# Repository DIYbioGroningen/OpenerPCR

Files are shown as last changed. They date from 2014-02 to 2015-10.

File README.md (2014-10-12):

OpenerPCR is a project by DIYbio Groningen to create an open PCR machine (also called a thermocycler). OpenerPCR is inspired by the OpenPCR project.

 * [Bill of materials](bill_of_materials.md)

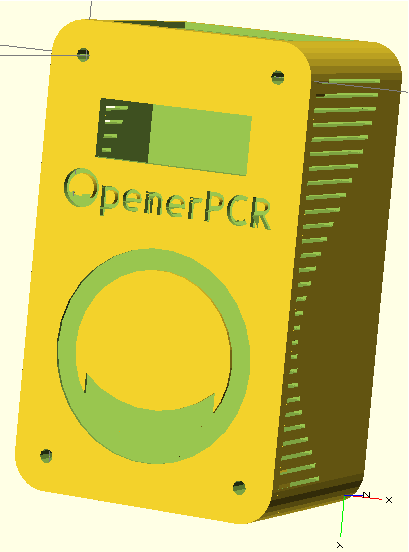
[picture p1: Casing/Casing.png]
Casing

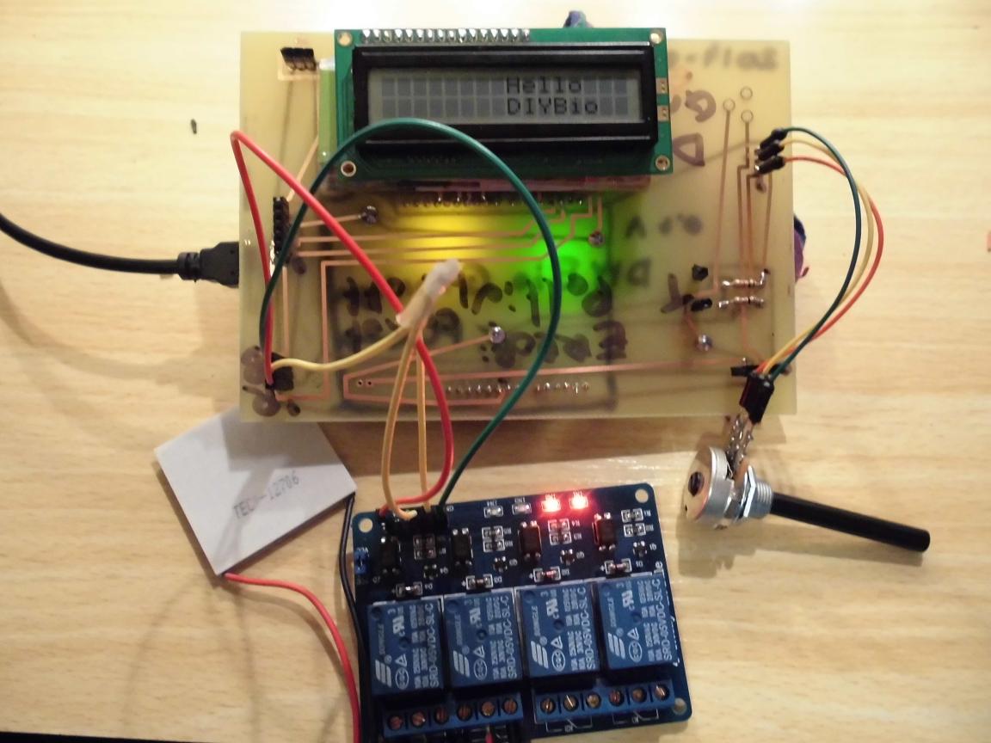
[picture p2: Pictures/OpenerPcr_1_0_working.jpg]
Working

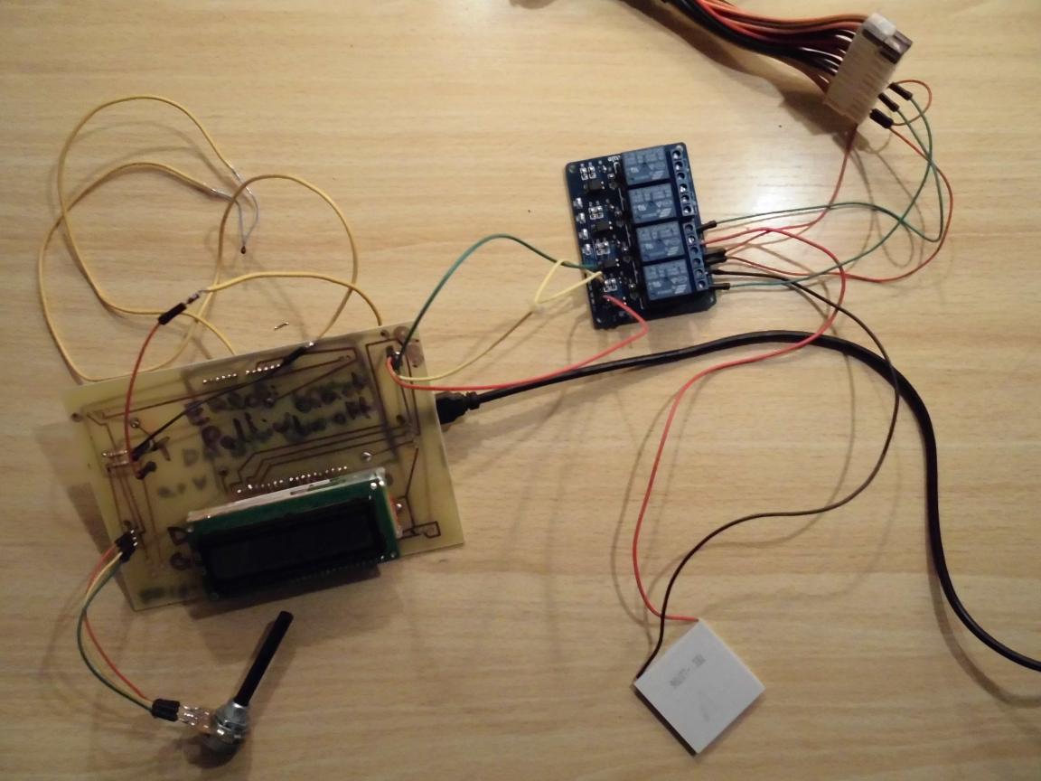
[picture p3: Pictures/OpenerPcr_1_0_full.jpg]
Full

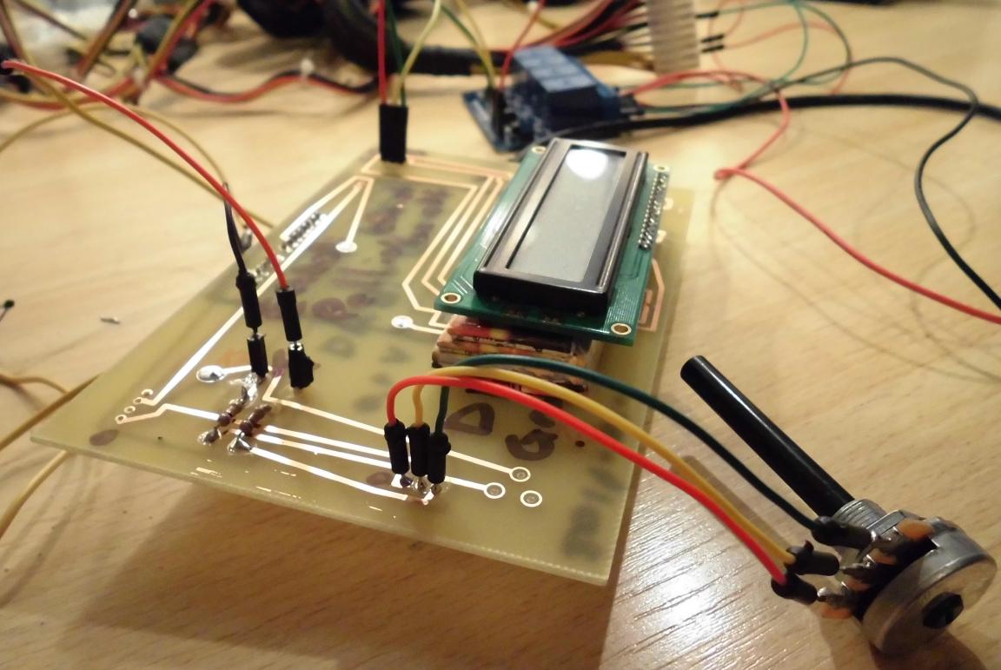
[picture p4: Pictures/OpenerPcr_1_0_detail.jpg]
Detail


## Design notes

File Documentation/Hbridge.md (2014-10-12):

# H bridge

The Pelter elements needs direct current. The direction of that current determines if a Peltier side cools or heats. The OpenerPCR needs to be able to let the Peltier cool and heat, so the current through the Peltier needs to be reversed. An H bridge can be used to achieve this.

There are multiple ways to create an H bridge: amongst others, using relays and using transistors. For the OpenerPCR project we chose to use relays (for now).

```
Signal
  |
+-+--+
|    |
|    A-  
|    |
|    B-
|    |
|    C-
|    |
+-+--+
  |
 GND
```

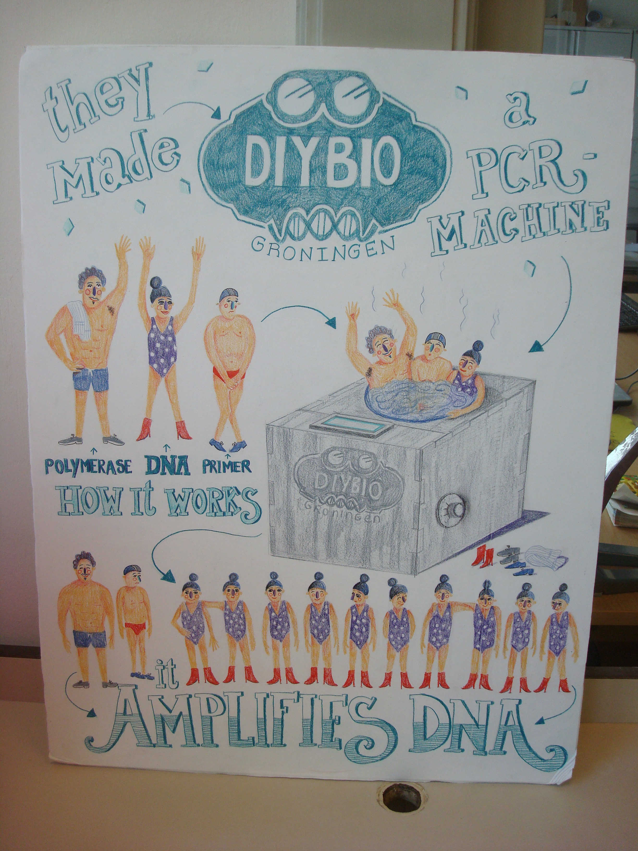
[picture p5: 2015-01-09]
Pictures/DIYBio_OpenerPCR_illustration.JPG

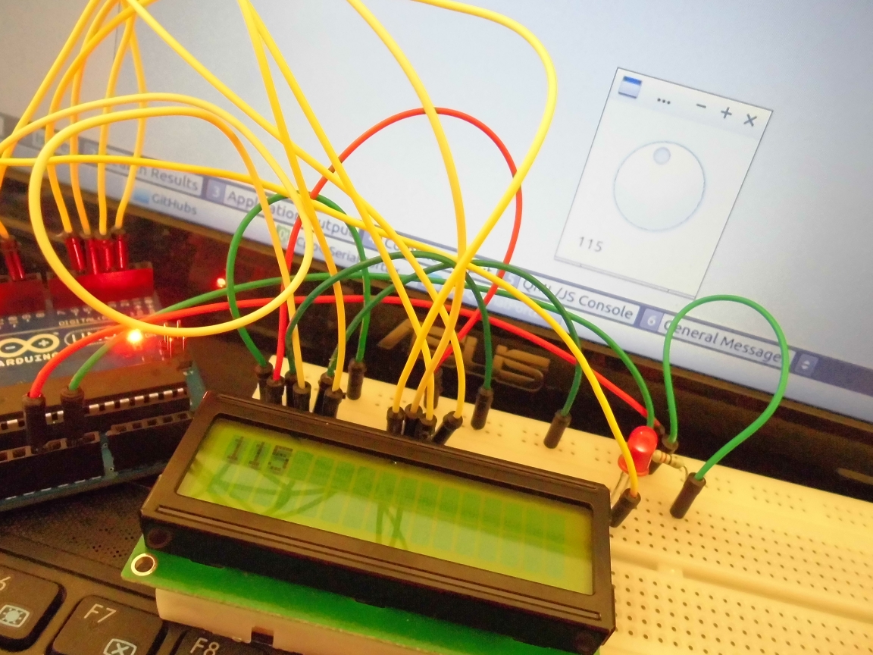
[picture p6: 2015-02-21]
Misc/Communication20141222.jpg

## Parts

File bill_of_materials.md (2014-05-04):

Bill Of Materials 
=================

Consist of components and autonomous parts

Components
----------

# Active/passive components

<table>
  <tr>
    <td>#</td><td>Brand official </td><td>Serial #</td><td>Description</td><td>SMD</td><td>What we really bought</td>
  </tr>
  <tr>
    <td>2</td><td>Yageo</td><td>SQP10AJB-4R7</td><td>Resistor, 4.7 Ohm, 10 W</td><td>No</td><td><a href="http://www.conrad.nl/ce/nl/product/411850/Draadweerstand-11W-47Ohm-Axiaal-Hoge-belasting-47-11-W-10-">Conrad</a></td>
  </tr>
  <tr>
    <td>1</td><td>Panasonic</td><td>ERG-2SJ160</td><td>Resistor, 16 Ohm </td><td>No</td><td>3 resistors circuit: (10 + 22) + 10</td>
  </tr>
  <tr>
    <td>2</td><td>Yageo</td><td>MFP-25BRD52-2K2</td><td>Resistor, 2.2k Ohm, 0.1%</td><td>No</td><td>Resistor, 2.2k Ohm, 1%</td>
  </tr>
  <tr>
    <td?1</td><td>Tyco</td><td>282834-6</td><td>Terminal block, 6 connector</td><td>No</td><td> </td>
  </tr>
  <tr>
    <td>2</td><td>Panasonic</td><td>ERJ-3GEYJ332V</td><td>Resistor, 3.3k Ohm</td><td>Yes</td><td>3 resistors circuit: (22K + 22K) + 22</td>
  </tr>
  <tr>
    <td>4</td><td>Panasonic</td><td>ERJ-3GEYJ102V</td><td>Resistor, 1k Ohm</td><td>Yes</td><td>As is</td>
  </tr>
  <tr>
    <td>1</td><td>Panasonic</td><td>ERG-1SJ510</td><td>Resistor, 51 Ohm, 1 W</td><td>No</td><td><a href="http://www.okaphone.com/artikel.asp?id=468110 Okaphone RC56E">Okaphone</a>: Resistor, 56 Ohm, 1 W</td>
  </tr>
  <tr>
    <td>1</td><td>Fairchild</td><td>RFD3055LE</td><td>Transistor, MOSFET N-Ch</td><td>No</td><td>  </td>
  </tr>
  <tr>
    <td>1</td><td>Microchip</td><td>MCP3551-E/SN</td><td>ADC, 22 bit</td><td>No</td><td><a href="ttp://www.okaphone.com/artikel.asp?id=476677 Okaphone MCP3551-E/MS">Okaphone</a></td>
  </tr>
  <tr>
    <td>1</td><td> Panasonic</td><td> ECA-1CM332</td><td> Capacitor, 3300 uF</td><td> No</td><td><a href="http://www.conrad.nl/ce/nl/product/421937/Panasonic-Radiale-condensator-serie-FC-EEUFC1C332-x-h-125-mm-x-35-mm-Rastermaat-5-mm-3300-F-16-V">Conrad</a></td>
  </tr>
  <tr>
    <td>1</td><td>Panasonic</td><td>ECA-1CM102</td><td>Capacitor, 1000 uF</td><td>No</td><td><a href="http://www.conrad.nl/ce/nl/product/441666/Panasonic-Radiale-elektrolytische-condensator-ECA-ECA1CM102-x-l-10-mm-x-16-mm-Rastermaat-5-mm-1000-F-16-V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">Conrad</a></td>
  </tr>
  <tr>
    <td>1</td><td>ST</td><td>VNH3SP30</td><td>H-Bridge IC</td><td>Yes</td><td><a href="http://www.okaphone.com/artikel.asp?id=476678 Okaphone VNH3SP30-E">Okaphone</a></td>
  </tr>
  <tr>
    <td>1</td><td>Custom</td><td></td><td>Peltier, Qmax = 84 W, dT = 78 K, Imax = 7.8 A</td><td>No</td><td><a href="http://www.okaphone.com/artikel.asp?id=471426">Okaphone (PELTIER 21)</a>: Qmax = 71 W, dT = 67 K, Imax = 8.0 A</td>
  </tr>
  <tr>
    <td>1</td><td>US Sensor</td><td>USP11553 rev none</td><td>Thermistor / PTC</td><td>No</td><td>HEISSLEITER S861/5K/1%/F40, 541-086-23, 500670, EAN: ...46 6996 O (the character capital-O)  3/18, 10671-348, 9549804009 546432717</td>
  </tr>
  <tr>
    <td>1</td><td>Custom</td><td> </td><td>Kapton Heater, 25 W, 11.3 V</td><td>No</td><td> </td>
  </tr>
</table>

#Autonomous parts

Things to connect components with/on/to

<table>
  <tr>
    <td># </td><td>Part</td><td>What we really bought
  </tr>
  <tr>
    <td>1</td><td>Arduino Uno</td><td>As is</td>
  </tr>
  <tr>
    <td>1</td><td>MicroATX power supply, 200 W, 14 A on 12 V rail, fan temperature control disabled, 24 pin ATX connector only</td><td>Scavanged</td>
  </tr>
  <tr>
    <td>1</td><td>Ribbon cable, 16 pin, female - female, 24"</td><td>?Hive5</td>
  </tr>
  <tr>
    <td>1</td><td>LCD, HD44780 compatible, 20 chars, 4 rows, blue backlight</td><td> <a href="http://www.okaphone.com/artikel.asp?id=421513 Okaphone LCD1602LC">Okaphone</a>: LCD 16 chars, 2 rows</td>
  </tr>
  <tr>
    <td>1</td><td>PCB</td><td>Etched, in possession</td>
  </tr>
  <tr>
    <td>1</td><td>USB Cable, A to B, 6 feet</td><td>In possession</td>
  </tr>
  <tr>
    <td>1</td><td>PSU Power Cord, USA plug, 6 feet</td><td> </td>
  </td>
</table>

Original wiring of HD44780 compatible LCD display OpenPCR used [http://en.wikipedia.org/wiki/Hitachi_HD44780_LCD_controller#Architecture Wikipedia]:

```
1    Ground
2    VCC (+3.3 to +5V)
3    Contrast adjustment (VO)
4    Register Select (RS). RS=0: Command, RS=1: Data
5    Read/Write (R/W). R/W=0: Write, R/W=1: Read
6    Clock (Enable). Falling edge triggered
7    Bit 0 (Not used in 4-bit operation)
8    Bit 1 (Not used in 4-bit operation)
9    Bit 2 (Not used in 4-bit operation)
10    Bit 3 (Not used in 4-bit operation)
11    Bit 4
12    Bit 5
13    Bit 6
14    Bit 7
15    Backlight Anode (+)
16    Backlight Cathode (-)
```

The LCD that was ordered has exactly the same interface (that is: its pins serve exactly the same function)

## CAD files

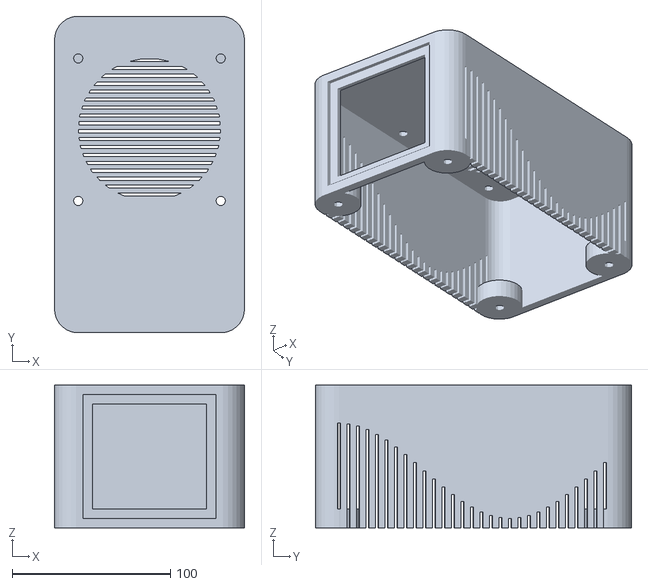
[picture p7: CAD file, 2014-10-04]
Casing/BackPanel.stl
120.0 x 199.8 x 90.0

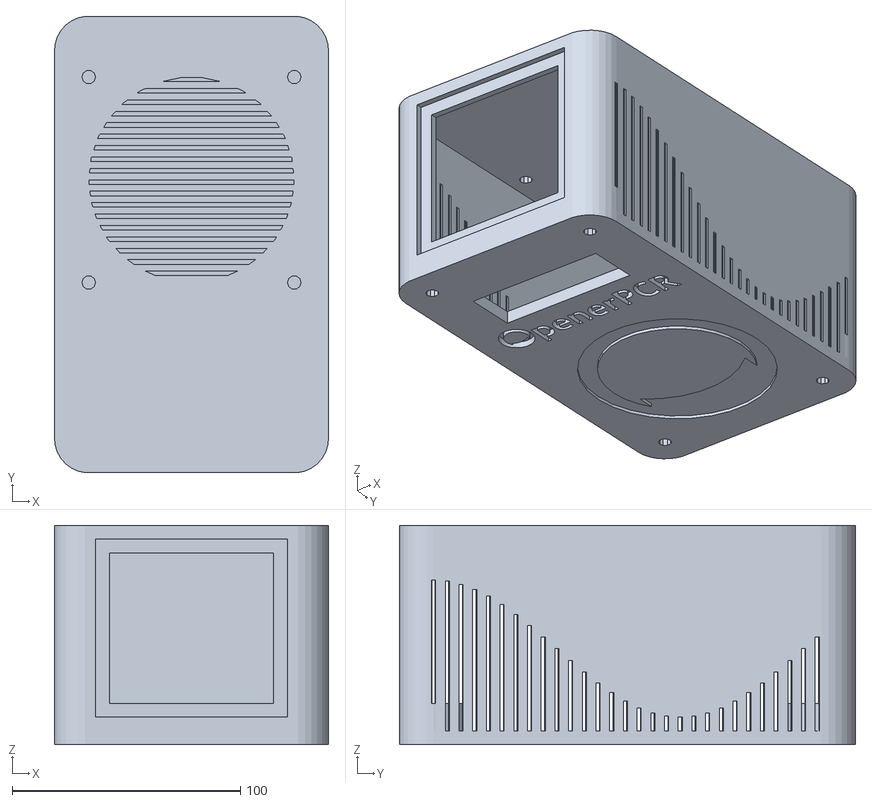
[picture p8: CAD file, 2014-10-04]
Casing/OpenerPCR.stl
120.0 x 199.8 x 96.0

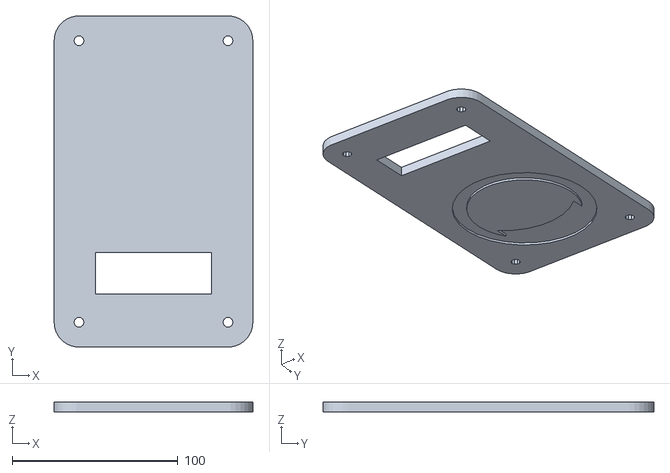
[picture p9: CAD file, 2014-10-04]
Casing/FrontPanel.stl
120.0 x 199.8 x 6.00

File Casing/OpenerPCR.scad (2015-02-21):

// OpenerPCR case.
// Ver 0.3.1
// by DIYbio Groningen
include <OpenrPCR_logo.scad>

//Build options
has_front = true;
has_back = false;
has_components = true;
has_leds = true;

W =  90; //Inner width of the casing in mm
H = 170; //Inner height of the casing in mm
Z =  90; //Inner depth of the casing in mm
Tk = 3;  //Thickness of casing material in mm, e.g. perspex is 3 mm
cr = 15; //Corner radius in mm
total_H = H+2*cr; //Outer height of the casing in mm
total_W = W+2*cr; //Outer width of the casing in mm
LCD_H = 25; //Width of the LCD display in mm
LCD_W = 70; //Height of the LCD display in mm
LCD_D = 19; //Depth of the LCD display in mm

shr = 3; //Screw hole radius in mm
offset = cr < 1 ? Tk+shr : 0; //The least distance a screw hole must be from the side
fd = 90; //Fan diameter in mm
Pcb_W_outer =  90; //Outer width of PCB in mm, the width of the box of air the PCB is in
Pcb_H_outer = 170; //Outer height of PCB in mm, the height of the box of air the PCB is in
Pcb_D_outer =  40; //Outer depth of PCB in mm, the depth of the box of air the PCB is in
Pcb_W = Pcb_W_outer; //Width of PCB in mm, the width of the box of air the PCB is in
Pcb_H = Pcb_H_outer; //Height of PCB in mm, the height of the box of air the PCB is in
Pcb_D = 2; //Depth of PCB in mm, the depth of the box of air the PCB is in
led_radius = 1.5; //Radius of an LED in mm
led_spacing = 10; //Distance between two LEDs in mm

module led_hole(){
  cylinder(h=4*Tk, r=led_radius);
}

module screw_hole(){
  cylinder(h=4*Tk, r=shr);
}

module screw_holder(){
  difference(){
    cylinder(h=4*Tk, r=cr);
    translate([0,0,-Tk]){
      cylinder(h=6*Tk, r=shr);
    }
  }  
}

module LCD_hole(){
  cube(size = [LCD_W,LCD_H,4*Tk]);
}

module panel(){
  minkowski(){
    cube([W,H,Tk]);
    // rounded corners
    cylinder(h=Tk,r=cr);
  }
}

module OpenerPCR_logo()
{
  difference(){
    cylinder(Tk,W/2,W/2);
    translate([0,0,-Tk]){
      cylinder(4*Tk,W/2.5,W/2.5);
    }
  }
  difference(){
    translate([-W/3,-W/10,0]){
      cube([W/1.5,W/2,Tk]);
    }
    translate([0,-W/4,-Tk]){
      cylinder(4*Tk,W/2,W/2);
    }
    translate([-W/3,W/2,-Tk]){
      cylinder(4*Tk,W/6,W/6);
    }
    translate([W/3,W/2,-Tk]){
      cylinder(4*Tk,W/6,W/6);
    }
  }
}

module plus_symbol(){
	cube([1,led_radius,Tk]);
	rotate([0,0,90]){
		cube([1,led_radius,Tk]);
	}
}

module power_symbol(){
	cylinder(Tk,led_radius*2,led_radius*2);
	difference(){
    	translate([0,0,-Tk]){
      	cylinder(Tk,led_radius*2,led_radius*2);
    	}
	}
	translate([-0.5,-led_radius*3,0]){
		cube([1,led_radius*2,Tk]);
	}
}

module front_panel(){
  difference(){  
    panel();
    // LCD window
    translate([(W-LCD_W)/2,0.1*H,-Tk]){
      LCD_hole();  
    }
    // Screw-holes
    translate([offset,offset,-Tk]){ // top-left
      screw_hole();  
    }
    translate([W-offset,offset,-Tk]){ // top-right
      screw_hole();    
    }
    translate([offset,H-offset,-Tk]){ // bottom-left
      screw_hole();  
    }
    translate([W-offset,H-offset,-Tk]){ // bottom-left
      screw_hole();
    }
    translate([W/2,H/1.4,-0.5*Tk]){
      OpenerPCR_logo();
    }
    if (has_leds) {
      translate([(W/2) +           0,(H/1.4) +           0,-0.5*Tk]){ led_hole(); } //Center Center
      translate([(W/2) +           0,(H/1.4) + led_spacing,-0.5*Tk]){ led_hole(); } //Center Top
      translate([(W/2) +           0,(H/1.4) - led_spacing,-0.5*Tk]){ led_hole(); } //Center
      translate([(W/2) - led_spacing,(H/1.4) +           0,-0.5*Tk]){ led_hole(); } //Left top
      translate([(W/2) - led_spacing,(H/1.4) - led_spacing,-0.5*Tk]){ led_hole(); } //Left bottom
      translate([(W/2) + led_spacing,(H/1.4) +           0,-0.5*Tk]){ led_hole(); } //Right top
      translate([(W/2) + led_spacing,(H/1.4) - led_spacing,-0.5*Tk]){ led_hole(); } //Right bottom
      /*

     5V          5V
     |           |
     O  +--O--+  O
     |  |     |  |
     |  | MMM |  |
     +--+-MMM +--+
     |  | MMM |  |
     |  |     |  |
     O  +--O--+  O
     |           |
     GND        GND

      */
      difference() { translate([(W/2) - (1.0 * led_spacing),(H/1.4) - (0.5 * led_spacing),-0.5*Tk]){ cube([2 * led_spacing,1,Tk]); }} //Center line
      difference() { translate([(W/2) - (0.25 * led_spacing),(H/1.4) - (0.75 * led_spacing),-0.5*Tk]){ cube([0.5 * led_spacing,0.5 * led_spacing,Tk]); }} //Motor

      difference() { translate([(W/2) - (0.5 * led_spacing),(H/1.4) - led_spacing,-0.5*Tk]){ cube([led_spacing,1,Tk]); }} //Top line
      difference() { translate([(W/2) - (0.5 * led_spacing),(H/1.4) +           0,-0.5*Tk]){ cube([led_spacing,1,Tk]); }} //Bottom line
      difference() { translate([(W/2) - (0.5 * led_spacing),(H/1.4) - led_spacing,-0.5*Tk]){ cube([1,led_spacing + 1,Tk]); }} //Left line
      difference() { translate([(W/2) + (0.5 * led_spacing),(H/1.4) - led_spacing,-0.5*Tk]){ cube([1,led_spacing + 1,Tk]); }} //Right line

      difference() { translate([(W/2) - (1.0 * led_spacing),(H/1.4) - (1.5 *led_spacing),-0.5*Tk]){ cube([1,2 * led_spacing,Tk]); }} //Left longer 5 V and GND line
      difference() { translate([(W/2) + (1.0 * led_spacing),(H/1.4) - (1.5 *led_spacing),-0.5*Tk]){ cube([1,2 * led_spacing,Tk]); }} //Right longer 5 V and GND line

		difference() { translate([(W/2) +           0,(H/1.4) + (1.75 *led_spacing),-0.5*Tk]){ power_symbol(); }} //power symbol
		difference() { translate([(W/2) - led_spacing,(H/1.4) +           0,-0.5*Tk]) { plus_symbol(); }} //plus symbol
    }
  }
}

module top_hole(){
  union(){
    // Top outer
    translate([Tk,-cr,3*Tk]){
      cube([W-2*Tk,Tk,Z-4*Tk]);
    }
    // Top inner
    translate([3*Tk,-cr,5*Tk]){
      cube([W-6*Tk,4*Tk,Z-8*Tk]);
    }
  }
}

module fan_holes(){
  // fan exaust
  difference(){
    cylinder(h=4*Tk,r=fd/2);
    for(i = [0:fd/5]){
      translate([-fd/2,-fd/2+(5*i),-Tk]){
        cube([fd,3,8*Tk]);
      }  
    }
  }
  // fan screws
  translate([-fd/2,+fd/2,0]){ // top-left
     screw_hole();  
  }
  translate([fd/2,+fd/2,0]){ // top-right
      screw_hole();    
  }
  translate([-fd/2,-fd/2,0]){ // bottom-left
      screw_hole();  
  }
  translate([fd/2,-fd/2,0]){ // bottom-left
      screw_hole();
  }
}

module air_intake(){
  rotate([0,0,90]){
    for(j=[0:2*Tk]){
      translate([0,-j,0]){
        for(i=[0:H/6]){
            translate([i*2*Tk,cr,Tk]){
                 cylinder(h=cos(i*10)*(Z/3)+(Z/2.5),r=Tk/3);
          }
        }
      }
    }
  }  
}  

// Body
module body(){
  difference(){    
    // Solid
    translate([0,0,Tk])  {
      minkowski() {
          cube([W,H,Z-Tk]);
          // rounded corners
          cylinder(r=cr,h=Tk);
        // al rounded
        //sphere(cr);
      }
    }  
    // Void
    translate([Tk,Tk,0]){
      minkowski() {
          cube([W-2*Tk,H-2*Tk,Z-2*Tk]);
          // rounded corners
          cylinder(r=cr-Tk,h=Tk);
      }
    }
    top_hole();
    air_intake();
    translate([W+cr+(3*Tk),0,0]){
      air_intake();
    }
    translate([W-fd/2,H/1.5,Z-2*Tk]){
    fan_holes();
    }
  }
  difference(){
    union(){
      translate([0,0,Tk]){
        screw_holder();
      }
      translate([W,0,Tk]){
        screw_holder();
      }  
      translate([W,H,Tk]){
        screw_holder();
      }
      translate([0,H,Tk]){
        screw_holder();
      }
    }
    top_hole();
  }
}



//Building
if (has_front)
{
   //Complete casing
  difference(){
    translate([0,0,-Tk]){
      front_panel();
    }
    translate([W/2,H/3,0]){
      rotate([180,0,0]){
        scale([0.5,0.5,1]){
          OpenerPCR_full_logo(10);
        }
      }
    }
  }
}
if (has_back)
{
  body();
}

if (has_components)
{
  color([10,1,1]) {
    translate([0,0,Pcb_D_outer / 2]){
      //cube([Pcb_W_outer,Pcb_H_outer,Pcb_D_outer]);
      cube([Pcb_W,Pcb_H,Pcb_D]);
    }
  }
  color([10,1,1]) {
    translate([(W-LCD_W)/2,0.1*H,(Pcb_D_outer / 2) - LCD_D]) {
      cube([LCD_W,LCD_H,LCD_D]);
    }
  }
}

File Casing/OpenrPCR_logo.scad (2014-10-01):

// Module names are of the form poly_<inkscape-path-id>().  As a result,
// you can associate a polygon in this OpenSCAD program with the corresponding
// SVG element in the Inkscape document by looking for the XML element with
// the attribute id="inkscape-path-id".

// fudge value is used to ensure that subtracted solids are a tad taller
// in the z dimension than the polygon being subtracted from.  This helps
// keep the resulting .stl file manifold.
fudge = 0.1;

module OpenerPCR_full_logo(h)
{
  scale([25.4/90, -25.4/90, 1]) union()
  {
    difference()
    {
       linear_extrude(height=h)
         polygon([[-215.668828,21.809332],[-215.668828,-23.190668],[-208.168828,-23.190668],[-204.071954,-23.135981],[-201.818829,-22.871224],[-200.865703,-22.245356],[-200.668828,-21.107335],[-200.448515,-19.748891],[-200.210039,-19.423519],[-199.918828,-19.408377],[-194.396542,-22.105263],[-190.441557,-23.543437],[-186.953362,-24.003574],[-182.831448,-23.766348],[-176.849837,-22.774722],[-171.689116,-21.086617],[-167.314818,-18.664011],[-163.692475,-15.468879],[-160.787621,-11.463198],[-158.565788,-6.608942],[-156.992510,-0.868088],[-156.033318,5.797388],[-155.833974,10.097443],[-156.033606,14.285049],[-156.618309,18.314829],[-157.574177,22.141404],[-158.887304,25.719397],[-160.543787,29.003431],[-162.529720,31.948128],[-164.831198,34.508110],[-167.838484,36.926869],[-171.346294,38.959541],[-175.229888,40.578147],[-179.364530,41.754708],[-183.625483,42.461249],[-187.888008,42.669789],[-192.027369,42.352352],[-195.918828,41.480960],[-200.668828,40.005070],[-200.668828,53.407200],[-200.668828,66.809330],[-208.168828,66.809330],[-215.668828,66.809330],[-215.668828,21.809332]]);
       translate([0, 0, -fudge])
         linear_extrude(height=h+2*fudge)
           polygon([[-180.149648,28.365760],[-177.737884,26.950575],[-175.663584,24.902480],[-173.951073,22.293237],[-172.624679,19.194607],[-171.708726,15.678350],[-171.227541,11.816228],[-171.205450,7.680002],[-171.666778,3.341433],[-172.722055,-1.239392],[-174.314872,-4.731049],[-176.601924,-7.381602],[-179.739908,-9.439114],[-181.658081,-10.199428],[-183.924193,-10.744296],[-188.995729,-11.186690],[-193.945512,-10.764283],[-196.059432,-10.228151],[-197.764538,-9.475064],[-200.668828,-7.759453],[-200.668828,9.917985],[-200.668828,27.595420],[-196.918828,29.201310],[-193.301826,30.141755],[-189.001638,30.301047],[-184.467750,29.701583],[-180.149648,28.365760]]);
    }
    difference()
    {
       linear_extrude(height=h)
         polygon([[-292.676402,49.861430],[-296.773829,49.153341],[-300.799357,48.142543],[-308.572610,45.264800],[-315.871953,41.332172],[-322.573176,36.448628],[-328.552073,30.718138],[-333.684433,24.244673],[-337.846049,17.132202],[-339.524013,13.368830],[-340.912713,9.484695],[-341.960546,5.413134],[-342.706713,0.924130],[-343.151432,-3.831242],[-343.294922,-8.701907],[-343.137401,-13.536789],[-342.679088,-18.184813],[-341.920200,-22.494906],[-340.860957,-26.315990],[-338.243912,-32.844822],[-335.048399,-38.860571],[-331.277684,-44.359908],[-326.935033,-49.339502],[-322.023711,-53.796023],[-316.546984,-57.726142],[-310.508117,-61.126527],[-303.910377,-63.993848],[-300.040401,-65.175311],[-295.629995,-66.039820],[-290.851829,-66.585213],[-285.878570,-66.809330],[-280.882886,-66.710007],[-276.037446,-66.285084],[-271.514917,-65.532398],[-267.487969,-64.449788],[-260.969775,-61.861106],[-254.885930,-58.628308],[-249.271777,-54.785638],[-244.162655,-50.367344],[-239.593906,-45.407670],[-235.600869,-39.940861],[-232.218886,-34.001164],[-229.483298,-27.622823],[-228.489269,-24.240553],[-227.710529,-20.252188],[-226.832707,-11.230287],[-226.917402,-2.103343],[-227.341810,2.016327],[-228.032188,5.582424],[-229.636911,10.807728],[-231.720413,15.881074],[-234.248563,20.753628],[-237.187229,25.376558],[-240.502279,29.701031],[-244.159581,33.678212],[-248.125004,37.259270],[-252.364416,40.395370],[-256.735976,42.973753],[-261.510508,45.203376],[-266.581875,47.059314],[-271.843938,48.516645],[-277.190560,49.550445],[-282.515603,50.135791],[-287.712930,50.247761],[-292.676402,49.861430]]);
       translate([0, 0, -fudge])
         linear_extrude(height=h+2*fudge)
           polygon([[-248.171758,11.309332],[-245.996275,6.959994],[-244.376729,2.330702],[-243.316667,-2.496216],[-242.819638,-7.438434],[-242.889191,-12.413622],[-243.528874,-17.339453],[-244.742237,-22.133600],[-246.532828,-26.713735],[-249.934502,-32.637092],[-254.202804,-37.869044],[-259.197989,-42.333506],[-264.780311,-45.954394],[-270.810024,-48.655626],[-277.147382,-50.361116],[-283.652641,-50.994781],[-286.924562,-50.885904],[-290.186053,-50.480538],[-296.248584,-49.025167],[-301.901193,-46.831296],[-307.090240,-43.945757],[-311.762083,-40.415376],[-315.863080,-36.286985],[-319.339592,-31.607411],[-322.137977,-26.423483],[-324.204593,-20.782032],[-324.983920,-17.412992],[-325.459350,-13.846962],[-325.519240,-6.419732],[-324.425705,0.908060],[-323.459355,4.349794],[-322.220190,7.544820],[-319.702756,12.650621],[-317.977812,14.984333],[-317.394041,15.124838],[-316.986215,14.588139],[-316.668826,11.504220],[-316.668826,6.954219],[-310.918826,9.912469],[-304.932666,12.591067],[-298.930976,14.415152],[-292.593587,15.459144],[-285.600327,15.797463],[-278.909212,15.476287],[-272.776492,14.422759],[-266.767443,12.531441],[-260.447343,9.696897],[-254.197346,6.809332],[-253.814736,8.645269],[-253.637026,13.059332],[-253.378483,18.072295],[-253.185386,18.323382],[-252.911342,18.253340],[-252.061286,17.309332],[-248.171758,11.309332]]);
    }
    difference()
    {
       linear_extrude(height=h)
         polygon([[-122.934358,41.784550],[-128.026058,40.076433],[-132.483599,37.693146],[-136.293191,34.654234],[-139.441048,30.979240],[-141.913381,26.687709],[-143.696404,21.799184],[-144.776329,16.333211],[-145.139368,10.309332],[-144.684949,3.046438],[-144.087302,-0.123627],[-143.216365,-3.059781],[-142.052389,-5.817280],[-140.575625,-8.451380],[-136.604738,-13.570413],[-134.101181,-16.021810],[-131.393417,-18.142998],[-128.511627,-19.934166],[-125.485993,-21.395501],[-122.346699,-22.527192],[-119.123926,-23.329427],[-115.847856,-23.802395],[-112.548673,-23.946284],[-109.256558,-23.761281],[-106.001693,-23.247576],[-102.814261,-22.405357],[-99.724445,-21.234811],[-96.762426,-19.736127],[-93.958387,-17.909494],[-91.342510,-15.755099],[-88.944978,-13.273131],[-87.240845,-10.893758],[-85.761135,-8.039766],[-84.536267,-4.844939],[-83.596655,-1.443059],[-82.972718,2.032092],[-82.694872,5.446729],[-82.793533,8.667070],[-83.299118,11.559332],[-83.902088,13.809332],[-106.785458,13.809332],[-129.668828,13.809332],[-129.668828,16.661449],[-129.031265,19.696498],[-127.301712,22.905775],[-124.754866,25.891345],[-121.665428,28.255270],[-119.522128,29.222806],[-116.957922,29.905525],[-114.101241,30.304468],[-111.080513,30.420675],[-105.060633,29.809047],[-102.318340,29.083294],[-99.925718,28.078970],[-95.682608,25.848620],[-93.059298,31.025490],[-90.435978,36.202360],[-92.632428,37.980940],[-95.261723,39.557736],[-98.498848,40.851190],[-103.826324,41.797328],[-110.922504,42.315928],[-117.915733,42.335499],[-122.934358,41.784550]]);
       translate([0, 0, -fudge])
         linear_extrude(height=h+2*fudge)
           polygon([[-98.058378,-0.388394],[-98.777719,-2.932340],[-99.849483,-5.158864],[-101.264524,-7.061257],[-103.013698,-8.632808],[-105.087860,-9.866806],[-107.477865,-10.756541],[-110.174569,-11.295304],[-113.168828,-11.476382],[-116.081164,-11.284037],[-118.740909,-10.709452],[-121.143191,-9.756301],[-123.283140,-8.428259],[-125.155886,-6.729001],[-126.756558,-4.662199],[-128.080285,-2.231531],[-129.122198,0.559332],[-129.803608,2.809332],[-113.611218,2.809332],[-97.418828,2.809332],[-98.058378,-0.388394]]);
    }
    difference()
    {
       linear_extrude(height=h)
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

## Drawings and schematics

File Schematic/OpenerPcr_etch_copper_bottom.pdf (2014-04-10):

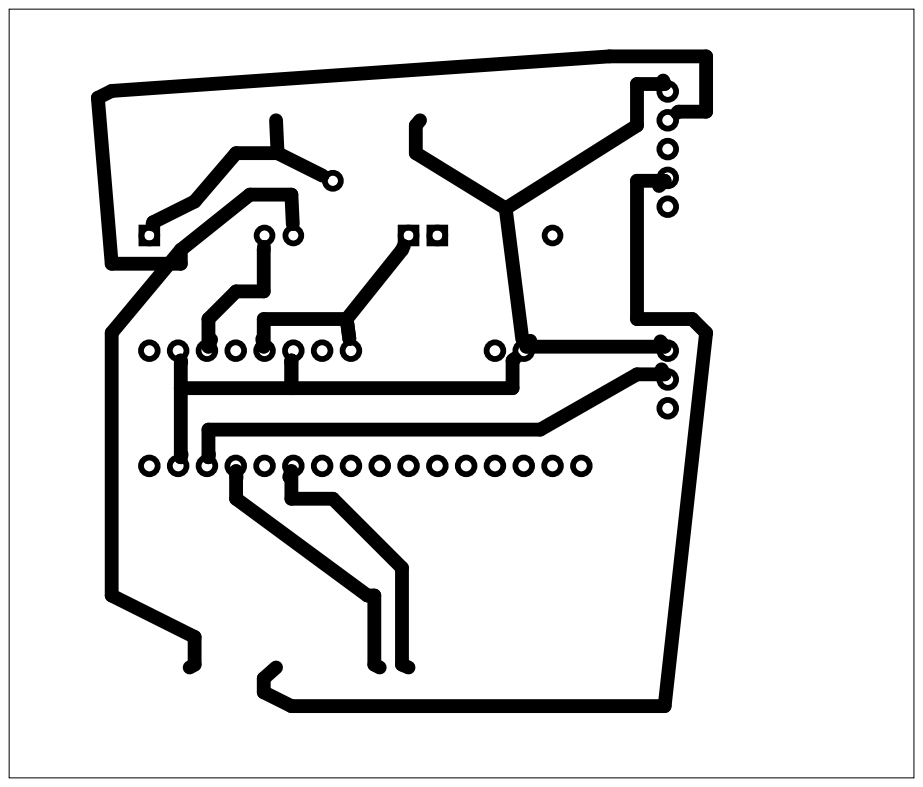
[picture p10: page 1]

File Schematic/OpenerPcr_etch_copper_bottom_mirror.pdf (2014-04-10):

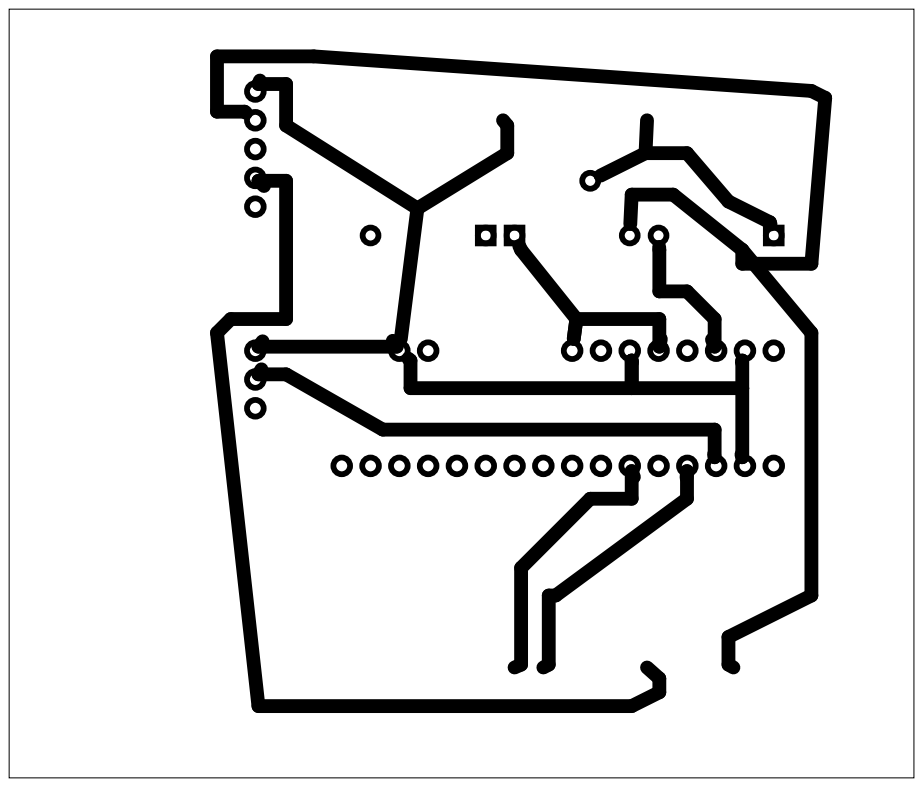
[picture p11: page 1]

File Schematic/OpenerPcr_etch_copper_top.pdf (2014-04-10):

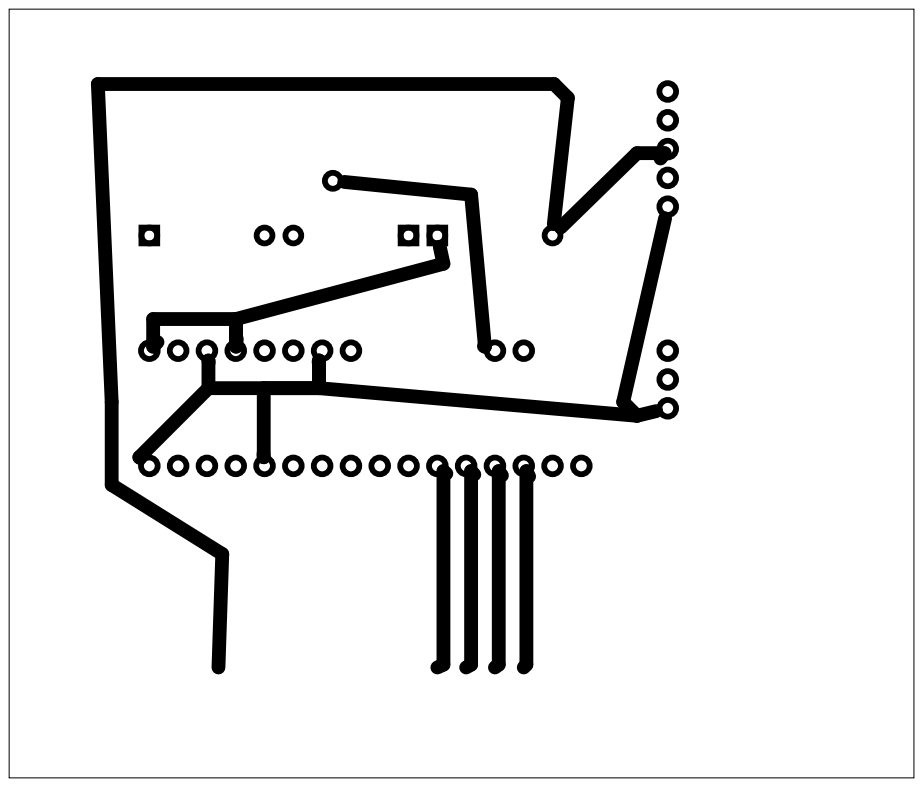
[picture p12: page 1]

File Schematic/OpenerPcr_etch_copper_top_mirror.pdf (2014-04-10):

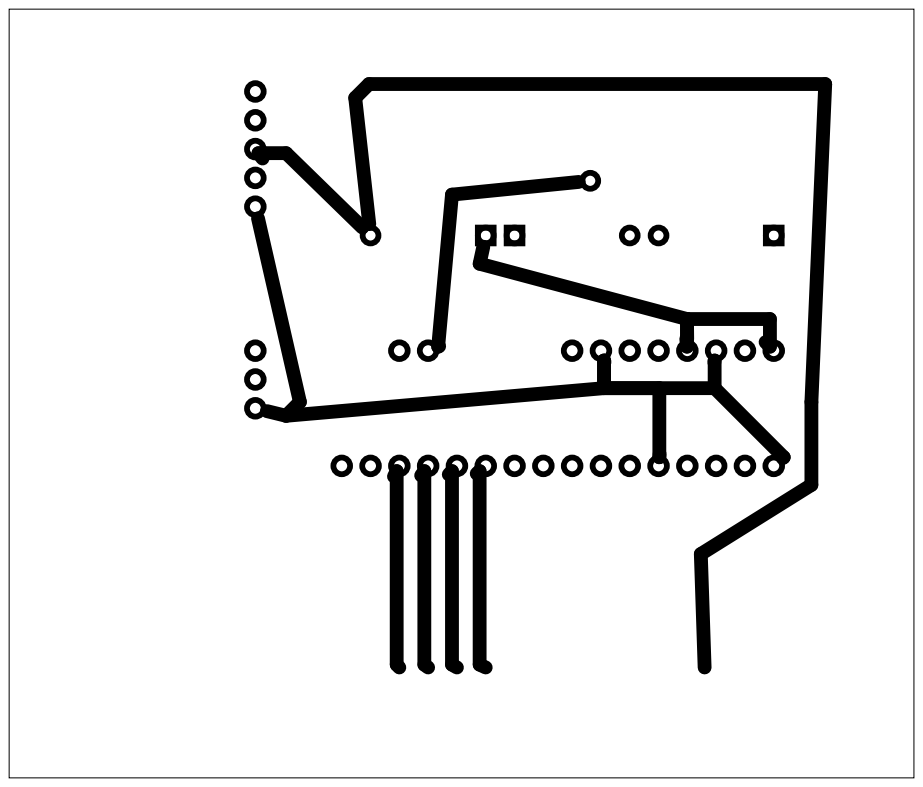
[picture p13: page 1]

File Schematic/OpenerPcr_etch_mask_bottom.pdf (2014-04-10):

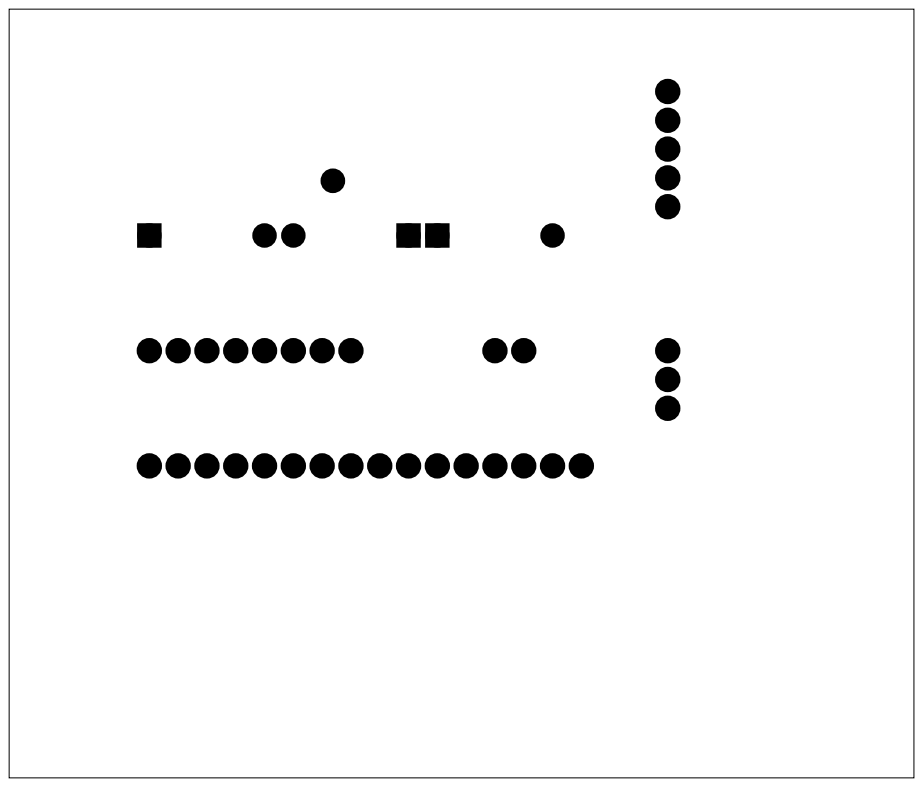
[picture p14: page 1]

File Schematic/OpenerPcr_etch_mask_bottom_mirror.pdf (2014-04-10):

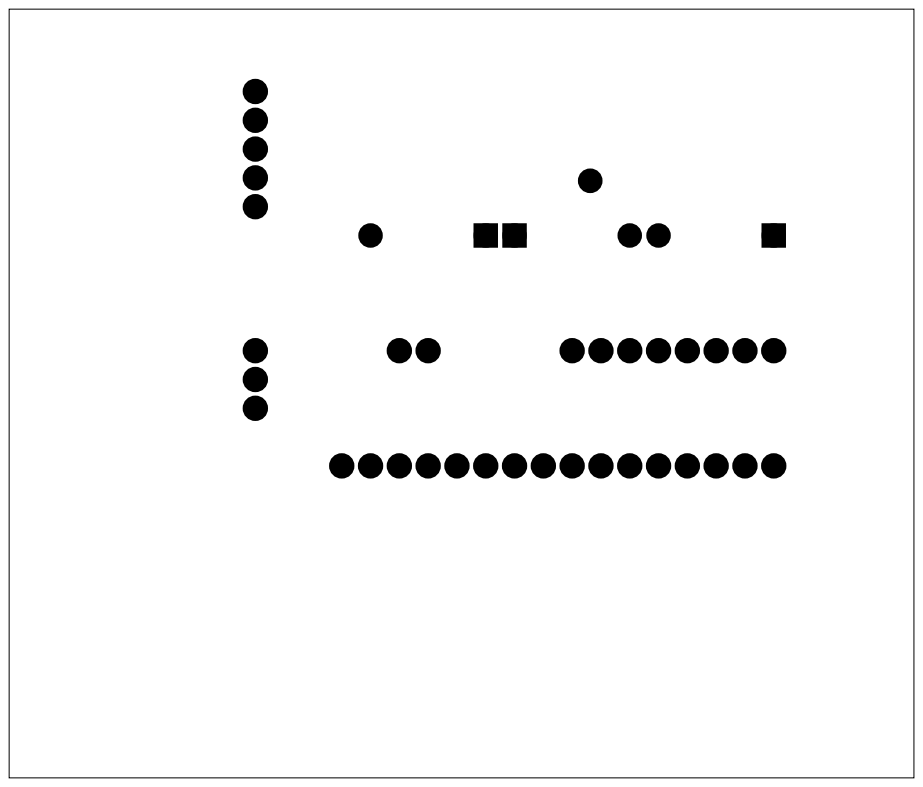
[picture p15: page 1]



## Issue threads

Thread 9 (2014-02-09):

Fritzing: find/design power source connector

richelbilderbeek, 2014-02-09:
I could not find the connector of the external power supply (2 rows of about 10 pins) in Fritzing. I need it for the PCB etch. Perhaps someone can find it somewhere or design it him/herself?

richelbilderbeek, 2021-04-21:
This is too long ago to do. Close!

Closed 2021-04-21.

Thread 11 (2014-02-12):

Add part list

richelbilderbeek, 2014-02-12:
Name: Fotogevoelige printplaat dubbelzijdig
Articlecode: PFD1
Price: € 5,95
Dimensions: 100 × 160 mm
http://www.okaphone.com/artikel.asp?id=449793

And others, from the wiki

richelbilderbeek, 2017-02-24:
I think this Issue has become obsolete.

Closed 2017-02-24.

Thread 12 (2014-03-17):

H bridge documentation

richelbilderbeek, 2014-03-17:
Uses the same setup as us, probably a good idea to add it to our documentation

https://nvhs.wordpress.com/project/catspberry/motor-controller/

richelbilderbeek, 2017-02-24:
I think this Issue has become irrelevant

Closed 2017-02-24.

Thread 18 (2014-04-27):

PCB: put the 10 kOhm resistance in the middle

richelbilderbeek, 2014-04-27:
So we cannot make mistakes

Closed 2015-12-31.

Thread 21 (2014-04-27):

Buy connector for power supply

richelbilderbeek, 2014-04-27:
to put on the PCB, will be obtained from Peter

richelbilderbeek, 2021-04-21:
Too long ago, let's close!

Closed 2021-04-21.

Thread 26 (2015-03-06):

Describe current PCR device

richelbilderbeek, 2015-03-06:
We have a Perkin-Elmer DNA Thermal Cycler 480 at DJO. We have also a bag with some thin walled Eppendorf cups and oil to prevent evaporation and condensation on the lid.

richelbilderbeek, 2021-05-14:
DIYBioGroningen has gone dormant, closing this Issue :-)

Closed 2021-05-14.

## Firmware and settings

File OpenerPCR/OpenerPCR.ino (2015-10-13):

///////////////////////////////////////////////////////////////////
//DIYBio-Groningen. Copyleft.
//version 1.0: the circuit schematic of the high power side is redrawn,
//so that in case the Arduino fails/goes off the Peltier element
//does NOT heat NEITHER cool.
///////////////////////////////////////////////////////////////////
//CIRCUIT SCHEMATIC
//JUMPER between JC-VCC and VCC on the relay board is removed:
//the relays are physically isolated from the control side
//of the circuit.
//The relay board is supplied with external +5VDC connected
//to JD-Vcc and external Ground to board GND.
//The Arduino controls two relays through IN1 and IN2 (signal pin)
//and one common VCC pin (Adruino +5VDC).
//
//The relay board connections on the high power side are illustrated below:
//NO: normally open
//NC: normally closed
//TEC: thermoelectric element
//
//         Relay1                  Relay2
//           *                       *
//          /|\                     /|\
//         / | \                   / | \
//      NO/  |  \NC             NO/  |  \NC
//       |   |   |     _____     |   |   |
//       |   !___|_____|TEC|_____|___!   |
//       !_______|_______________!_______|_______ +12VDC
//               |                       |
//               !_______________________!_______ GND
//
//
// when Arduino pin is:
// LOW == relay Normally Open (NO) == LEDs on
// HIGH == relay Normally Close (NC) == LEDs off
///////////////////////////////////////////////////////////////////

// Pin 2 and 3 control the relay board: relay1 and relay2 respectively.
const int relay_pin1 = 2;
const int relay_pin2 = 3;
const int thermistor_pin = A0;

const double denaturation_temperature_celcius = 95.0;
const double annealing_temperature_celcius = 60.0;
const double extension_temperature_celcius = 72.0;

const double denaturation_time_secs = 30;
const double annealing_time_secs = 20;
const double extension_time_secs = 10;

void setup() {                
  pinMode(relay_pin1, OUTPUT);     
  pinMode(relay_pin2, OUTPUT);     
  pinMode(thermistor_pin,INPUT);
}


void cool() {
  //Relay1 NC
  //Relay2 NO
  //face#1 is cooling
  digitalWrite(relay_pin1, HIGH);
  digitalWrite(relay_pin2, LOW);
}

void heat() {
  //Relay1 NO
  //Relay2 NC
  //face#1 is heating
  digitalWrite(relay_pin1, LOW);
  digitalWrite(relay_pin2, HIGH);
}

double read_temperature() {
  const int value = analogRead(thermistor_pin);
  //Transform the range of value from [0,1023] to [0,100] degrees Celsius
  const double t_stub 
    = static_cast<double>(
     map(value,0,1023,0,100)
   );
  return t_stub;
}

void go_to_temperature(const double target_temperature_celsius)
{
  const double current_temperature = read_temperature();
  const double acceptable_temperature_difference_celsius = 1.0;
  if (abs(target_temperature_celsius - current_temperature) 
    < acceptable_temperature_difference_celsius)
  {
    return;
  }
  //Need to heat or cool to the target temperature
  if (target_temperature_celsius > current_temperature)
  {
    cool();
  }
  else 
  {
    heat(); 
  }
}

void loop() {
  go_to_temperature(denaturation_temperature_celcius);
  delay(denaturation_time_secs * 1000); //delay needs msecs
  
  go_to_temperature(annealing_temperature_celcius);
  delay(annealing_time_secs * 1000); //delay needs msecs
  
  go_to_temperature(extension_temperature_celcius);
  delay(extension_time_secs * 1000); //delay needs msecs
}

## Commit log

2014-01-29 Added tasks
    [OpenerPcrTask1.fzz, OpenerPcrTask2.fzz, OpenerPcrTask3.fzz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]
2014-02-01 PCB v. 1.1
    [OpenerPcr.fzz]
2014-02-01 Breadboard version 1.2
    [OpenerPcr.fzz]
2014-02-01 Added thermistor to code
2014-02-01 PCB version 1.3
    [OpenerPcr.fzz]
2014-02-01 Added thermistor calculation
2014-02-01 Better fit on thermistor values
2014-02-01 Improved schematic
    [OpenerPcr.fzz]
2014-02-09 Added pin for fan
    [OpenerPcr.fzz]
2014-02-12 Removed H-bridge breakout board pins
    [OpenerPcr.fzz]
2014-04-06 PCB has a fan, code uses fan (but this is not yet checked)
    [OpenerPcr.fzz]
2014-04-06 PCB has LEDs to indicate cooling/heating
    [OpenerPcr.fzz]
2014-04-17 Allow schematic to be viewable on non-Fablab computer
    [OpenerPcr.fzz]
2014-04-27 PCB v.1.6.2, removed incorrect wiring for heating/cooling LEDs
    [OpenerPcr.fzz, OpenerPcr2.fzz]
2014-05-01 DIYbio meeting 2014-04-25
    [OpenerPcr.fzz, OpenerPcr2.fzz]
2014-05-04 Added BOM
2014-07-28 Added power supply schematics under Misc
2014-09-14 Added OpenSCAD casing
    [OpenerPCR.scad]
2014-09-14 Added holes
    [OpenerPCR.scad]
2014-09-15 added logo, air intakes and screw holders
    [OpenerPCR.scad, OpenrPCR_logo.scad]
2014-09-15 Breakup in modules
    [OpenerPcr.fzz]
2014-10-04 Added different build m modes for casing, added comments to OpenSCAD file
    [BackPanel.stl, FrontPanel.stl, OpenerPCR.scad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]
2014-10-09 Added casing picture
    [OpenerPCR.scad]
2014-10-12 Arduino to standalone, e chip, put some components in casing, added debugging to PCB
    [OpenerPCR.scad, OpenerPcr.fzz]
2015-03-29 Added Piet and Claudio's excellent work
    [OpenerPcr.fzz, OpenerPcr~.fzz]
